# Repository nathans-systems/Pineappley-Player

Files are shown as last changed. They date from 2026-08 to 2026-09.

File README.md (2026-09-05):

# Pineappley-Player
My Open-Source, Custom built MP3 Player.
Using an ESP32-S3-Zero, cheap, available parts and a custom PCB I designed I've built a reliable and high quality audio playing MP3 Player.

picblack

## Hardware
- ESP32-S3-Zero
- 1.3 Inch I2C Oled
- Rotary Encoder
- TFT Micro SD Card Module
- KCX Bluetooth Emmiter
- TP4056 Charging Module
- MT3608 Boots Converter
- GY-PCM5102A
- 1800mah lithium battery
- Power Switch



## Key Features
- High Quality Audio
- Headphone Out
- Bluetooth Connectivity
- Micro SD card reader
- Rechargeable Battery



## Programming
The firmware is built on the PlatformIO and Arduino Framework.
You can upload and edit the firmware using Arduino C++ and flashing the ESP via the USB-C port under the OLED.

## PCB
I designed the PCB myself in KICAD. It features many through hole areas for each module, smd contacts for the KCX module and battery resistors and encoder capacitors.

## How Does it Work?
After loading your MP3 Files onto the SD card, the files are read over SPI to the ESP. After decoding, the PCM signal is sent over I2S to the PCM5102. The PCM5102 converts the digital audio to analog which can be read by the KCX Emitter.
The Pineappley Player utilises both cores of the ESP32-S3, forcing all audio tasks to core 0 to ensure clean audio as all other tasks such as drawing to the screen can run on core 1.

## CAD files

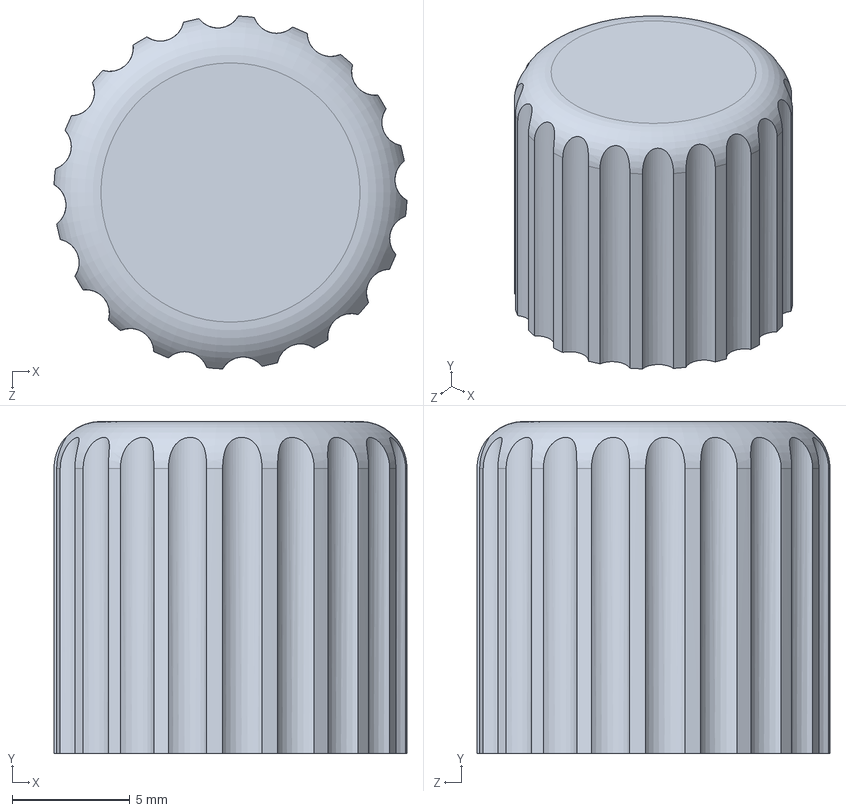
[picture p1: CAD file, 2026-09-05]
3D models/knob.SLDPRT
15.0 x 14.1 x 15.0 mm

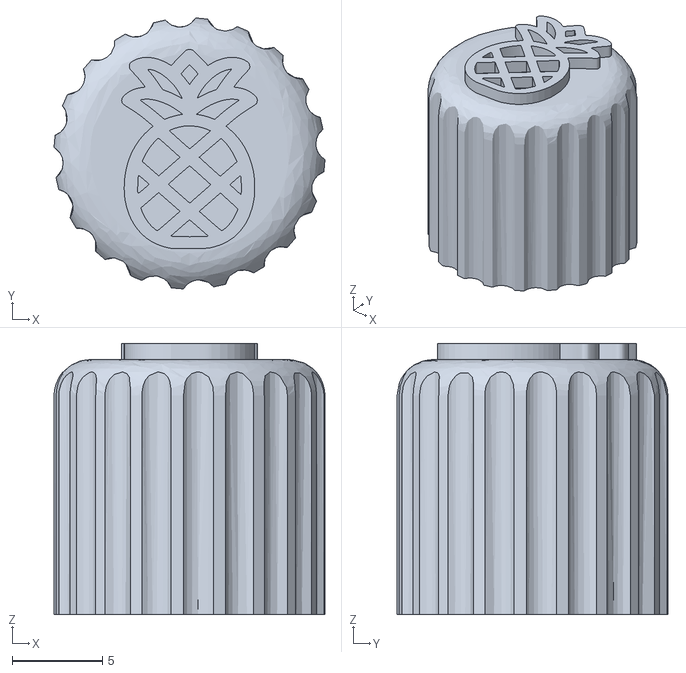
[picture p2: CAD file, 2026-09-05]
3D models/KnobWithLogo.stl
15.0 x 15.0 x 15.0

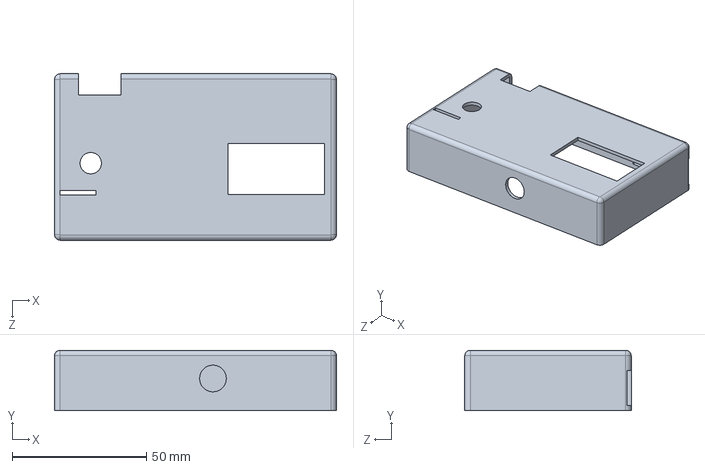
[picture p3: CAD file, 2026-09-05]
3D models/case.SLDPRT
105.0 x 22.5 x 62.0 mm

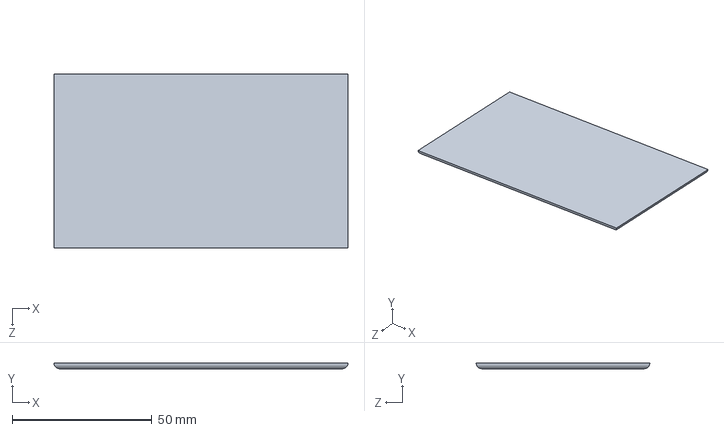
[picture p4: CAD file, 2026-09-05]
3D models/hatch.SLDPRT
105.0 x 2.00 x 62.0 mm

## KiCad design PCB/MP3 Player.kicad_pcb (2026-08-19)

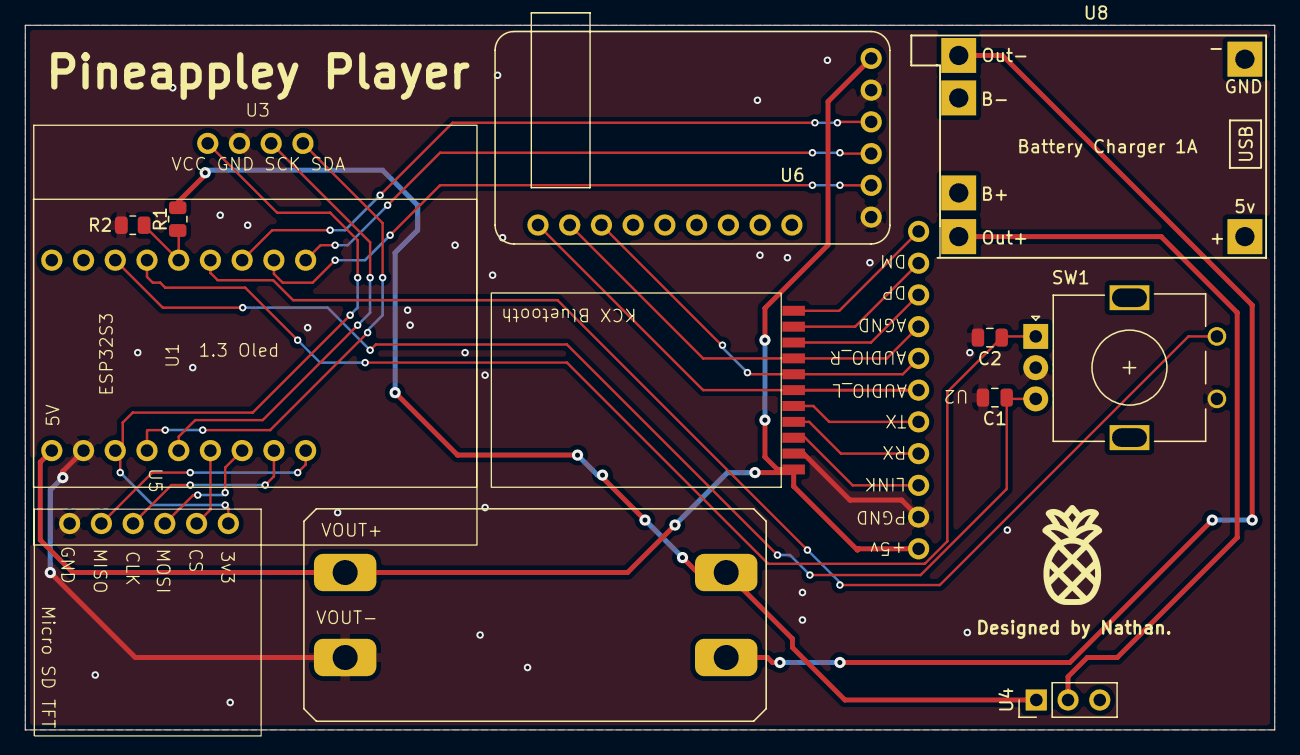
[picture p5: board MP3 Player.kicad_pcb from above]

Board: 2 copper layers, 100.0 x 56.4 mm, 13 parts (0 on the bottom side), 22 nets.

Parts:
C1, C2: 100nF; C_0805_2012Metric
R1, R2: 10K; R_0805_2012Metric
SW1: RotaryEncoder_Switch; RotaryEncoder_Alps_EC11E_Vertical_H20mm
U1: ESP32S3 MINI
U2: KCX Bluetooth
U3: 1.3 Oled
U4: PinHeader_1x03_P2.54mm_Vertical
U5: TFT MicroSD Module
U6: GY-PCM5102
U7: hw-045
U8: TP4056-18650

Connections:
+5V: U1.1 (5V), U2.1 (5V), U6.1 (VIN), U7.1 (VOUT+)
BAT+ OUT: R1.1, R2.2, U1.14 (GPIO11)
GND: C1.2, C2.2, R2.1, SW1.C, SW1.S2, U1.2 (GND), U2.2 (PGND), U3.2 (GND), U5.1 (GND), U6.2 (GND), U6.6 (SCK), U7.2 (VOUT-)
unnamed: U1.3 (3V3_OUT), U3.1 (VCC), U5.6 (3V3)
unnamed: U1.4 (GPIO1), U3.4 (SDA)
unnamed: U1.5 (GPIO2), U3.3 (SCK)
unnamed: U1.6 (GPIO3), U5.5 (CS)
unnamed: U1.7 (GPIO4), U5.4 (MOSI)
unnamed: U1.8 (GPIO5), U5.3 (CLK)
unnamed: U1.9 (GPIO6), U5.2 (MISO)
unnamed: U1.10 (GPIO7), U6.4 (DIN)
unnamed: U1.11 (GPIO8), U6.5 (BCK)
unnamed: U1.12 (GPIO9), U6.3 (LRCK)
unnamed: SW1.S1, U1.13 (GPIO10)
unnamed: C2.1, SW1.A, U1.15 (GPIO12)
unnamed: C1.1, SW1.B, U1.16 (GPIO13)
unnamed: U2.8 (AGND), U6.14 (AGND)
unnamed: U2.6 (AUDIO_L), U6.15 (LROUT)
unnamed: U2.7 (AUDIO_R), U6.13 (ROUT)
unnamed: U4.2 (IN), U8.1 (OUT+)
unnamed: R1.2, U4.1 (OUT), U7.3 (VIN+)
unnamed: U7.4 (VIN-), U8.4 (OUT-)

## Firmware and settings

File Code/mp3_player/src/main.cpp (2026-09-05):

#include <Arduino.h>
#include <Wire.h>
#include <SPI.h>
#include <SD.h>
#include <U8g2lib.h>
#include "Audio.h"
#include <vector>

#define OLED_SDA      1
#define OLED_SCL      2

#define SD_CS         3
#define SPI_MOSI      4
#define SPI_SCK       5
#define SPI_MISO      6

#define I2S_DOUT      7
#define I2S_BCLK      8
#define I2S_LRC       9

#define BATTERY_PIN   11

#define ENCODER_OUTA  12
#define ENCODER_OUTB  13
#define ENCODER_SW    10

enum UIState { SCREEN_MENU, SCREEN_PLAYER, SCREEN_SETTINGS };
UIState currentScreen = SCREEN_MENU;

enum PlayerButton { BTN_PREV, BTN_PLAY_PAUSE, BTN_NEXT, BTN_SHUFFLE, BTN_SEEK };
PlayerButton selectedPlayerBtn = BTN_PLAY_PAUSE;

enum SettingOption { SETTING_VOL_LIMIT, SETTING_BASS, SETTING_TREBLE, SETTING_BALANCE };
SettingOption selectedSetting = SETTING_VOL_LIMIT;
bool isSettingEditMode = false;

U8G2_SH1106_128X64_NONAME_F_HW_I2C u8g2(U8G2_R0, U8X8_PIN_NONE);
Audio audio;

std::vector<String> songList;
int currentTrackIndex = 0;
int playingTrackIndex = -1;
int menuScrollOffset = 0;
bool isPlaying = false;
bool isShuffle = false;

float maxVolumeLimit = 4.0f;
int bassBoost = 0;
int trebleBoost = 0;
int balanceLR = 0;

int currentVolume = 50;
bool showVolumeOverlay = false;

bool isSeeking = false;
uint32_t seekTargetSec = 0;

int batteryPercentage = 100;
float filteredVoltageMv = 0.0;
unsigned long lastBatteryCheck = 0;

void updateAudioVolume() {
  float targetVol = (currentVolume / 100.0f) * maxVolumeLimit;
  audio.setVolume(targetVol);
}

void applyEqualizerSettings() {
  audio.setTone(bassBoost, 0, trebleBoost);
  audio.setBalance(balanceLR);
}

int calculateLiPoPercentage(uint32_t mVolts) {
  const uint32_t MIN_VOLTAGE = 3200;
  const uint32_t MAX_VOLTAGE = 4200;

  if (mVolts >= MAX_VOLTAGE) return 100;
  if (mVolts <= MIN_VOLTAGE) return 0;

  return (int)(((float)(mVolts - MIN_VOLTAGE) / (MAX_VOLTAGE - MIN_VOLTAGE)) * 100.0f);
}

void readBatteryLevel() {
  uint32_t rawSum = 0;
  for (int i = 0; i < 32; i++) {
    rawSum += analogReadMilliVolts(BATTERY_PIN);
  }
  float currentPinMv = (float)rawSum / 32.0f;
  float currentBatMv = currentPinMv * 2.0f;

  if (filteredVoltageMv == 0.0) {
    filteredVoltageMv = currentBatMv;
  } else {
    filteredVoltageMv = (filteredVoltageMv * 0.85f) + (currentBatMv * 0.15f);
  }

  batteryPercentage = calculateLiPoPercentage((uint32_t)filteredVoltageMv);
}

void drawBatteryIndicator() {
  u8g2.setFont(u8g2_font_micro_tr);
  
  String pctStr = String(batteryPercentage) + "%";
  int textWidth = u8g2.getStrWidth(pctStr.c_str());
  int textX = 114 - textWidth; 
  u8g2.drawStr(textX, 8, pctStr.c_str());

  u8g2.drawFrame(115, 2, 11, 6);
  u8g2.drawVLine(126, 3, 4);

  int fillWidth = map(batteryPercentage, 0, 100, 0, 7);
  if (fillWidth > 0) {
    u8g2.drawBox(117, 4, fillWidth, 2);
  }
}

volatile int encoderStepDelta = 0; 
portMUX_TYPE encoderMux = portMUX_INITIALIZER_UNLOCKED;

void IRAM_ATTR encoderISR() {
  static uint8_t oldState = 0;
  static const int8_t knobStates[] = {0, -1, 1, 0, 1, 0, 0, -1, -1, 0, 0, 1, 0, 1, -1, 0};

  oldState <<= 2;
  if (digitalRead(ENCODER_OUTA)) oldState |= 0x02;
  if (digitalRead(ENCODER_OUTB)) oldState |= 0x01;
  oldState &= 0x0F;

  int8_t step = knobStates[oldState];
  if (step != 0) {
    portENTER_CRITICAL_ISR(&encoderMux);
    encoderStepDelta += step;
    portEXIT_CRITICAL_ISR(&encoderMux);
  }
}

bool lastRawBtnState = HIGH;
bool stableBtnState = HIGH;
unsigned long lastDebounceTime = 0;
const unsigned long DEBOUNCE_DELAY = 40;

unsigned long btnPressStartTime = 0;
int clickCount = 0;
unsigned long lastClickReleaseTime = 0;
bool longPressTriggered = false;

int marqueePosMenu = 0;
int marqueePosHeader = 0;
int marqueePosPlayer = 0;
unsigned long lastMarqueeUpdate = 0;

uint8_t barHeights[14] = {0};

const unsigned char epd_bitmap_pineapple_64x64 [] PROGMEM = {
  0x00, 0x00, 0x00, 0x00, 0x00, 0x00, 0x00, 0x00, 0x00, 0x00, 0x00, 0x80, 0x01, 0x00, 0x00, 0x00, 
  0x00, 0x00, 0x00, 0xc0, 0x03, 0x00, 0x00, 0x00, 0x00, 0x00, 0x7c, 0xe0, 0x07, 0x3e, 0x00, 0x00, 
  0x00, 0x00, 0xff, 0xf1, 0x8f, 0xff, 0x00, 0x00, 0x00, 0x80, 0xff, 0x7b, 0xde, 0xff, 0x01, 0x00, 
  0x00, 0x00, 0x8f, 0x3f, 0xfc, 0xf1, 0x00, 0x00, 0x00, 0x00, 0x0e, 0x1f, 0xf8, 0x70, 0x00, 0x00, 
  0x00, 0x00, 0x1c, 0x1c, 0x38, 0x38, 0x00, 0x00, 0x00, 0x00, 0x3c, 0x38, 0x1c, 0x3c, 0x00, 0x00, 
  0x00, 0x00, 0x38, 0x70, 0x0e, 0x1c, 0x00, 0x00, 0x00, 0x00, 0x70, 0xf0, 0x0f, 0x0e, 0x00, 0x00, 
  0x00, 0x00, 0xf0, 0xe0, 0x07, 0x0f, 0x00, 0x00, 0x00, 0x00, 0xff, 0xe0, 0x07, 0xff, 0x00, 0x00, 
  0x00, 0x80, 0xff, 0xc7, 0xe3, 0xff, 0x01, 0x00, 0x00, 0xc0, 0xe3, 0xcf, 0xf3, 0xc7, 0x03, 0x00, 
  0x00, 0xe0, 0x03, 0xfe, 0x7f, 0xc0, 0x07, 0x00, 0x00, 0xc0, 0x07, 0xf8, 0x1f, 0xe0, 0x03, 0x00, 
  0x00, 0x80, 0x0f, 0xf0, 0x0f, 0xf0, 0x01, 0x00, 0x00, 0x00, 0x1e, 0xe0, 0x07, 0x78, 0x00, 0x00, 
  0x00, 0x00, 0x3c, 0xc0, 0x03, 0x3c, 0x00, 0x00, 0x00, 0x00, 0x78, 0xc0, 0x03, 0x1e, 0x00, 0x00, 
  0x00, 0x00, 0xf0, 0xfc, 0x3f, 0x0f, 0x00, 0x00, 0x00, 0x00, 0xe0, 0xff, 0xff, 0x07, 0x00, 0x00, 
  0x00, 0x00, 0xc0, 0x1f, 0xf8, 0x03, 0x00, 0x00, 0x00, 0x00, 0xc0, 0x03, 0xc0, 0x03, 0x00, 0x00, 
  0x00, 0x00, 0xe0, 0x03, 0xc0, 0x07, 0x00, 0x00, 0x00, 0x00, 0xf0, 0x07, 0xe0, 0x0f, 0x00, 0x00, 
  0x00, 0x00, 0x38, 0x0f, 0xf0, 0x1c, 0x00, 0x00, 0x00, 0x00, 0x3c, 0x1e, 0x78, 0x3c, 0x00, 0x00, 
  0x00, 0x00, 0x1c, 0x3c, 0x3c, 0x38, 0x00, 0x00, 0x00, 0x00, 0x0e, 0x78, 0x1e, 0x70, 0x00, 0x00, 
  0x00, 0x00, 0x0e, 0xf0, 0x0f, 0x70, 0x00, 0x00, 0x00, 0x00, 0x07, 0xe0, 0x07, 0xe0, 0x00, 0x00, 
  0x00, 0x00, 0x07, 0xc0, 0x03, 0xe0, 0x00, 0x00, 0x00, 0x80, 0x03, 0xe0, 0x07, 0xc0, 0x01, 0x00, 
  0x00, 0x80, 0x03, 0xf0, 0x0f, 0xc0, 0x01, 0x00, 0x00, 0x80, 0x07, 0x78, 0x1e, 0xe0, 0x01, 0x00, 
  0x00, 0x80, 0x0f, 0x3c, 0x3c, 0xf0, 0x01, 0x00, 0x00, 0xc0, 0x1f, 0x1e, 0x78, 0xf8, 0x03, 0x00, 
  0x00, 0xc0, 0x39, 0x0f, 0xf0, 0x9c, 0x03, 0x00, 0x00, 0xc0, 0xf1, 0x07, 0xe0, 0x8f, 0x03, 0x00, 
  0x00, 0xc0, 0xe1, 0x03, 0xc0, 0x87, 0x03, 0x00, 0x00, 0xc0, 0xe1, 0x03, 0xc0, 0x87, 0x03, 0x00, 
  0x00, 0xc0, 0xf1, 0x03, 0xc0, 0x8f, 0x03, 0x00, 0x00, 0xc0, 0xf9, 0x07, 0xe0, 0x9f, 0x03, 0x00, 
  0x00, 0xc0, 0x3d, 0x0e, 0xf0, 0xbc, 0x03, 0x00, 0x00, 0xc0, 0x1f, 0x1c, 0x78, 0xf8, 0x03, 0x00, 
  0x00, 0xc0, 0x0f, 0x38, 0x3c, 0xf0, 0x03, 0x00, 0x00, 0x80, 0x07, 0x70, 0x1e, 0xe0, 0x01, 0x00, 
  0x00, 0x80, 0x03, 0xe0, 0x0f, 0xc0, 0x01, 0x00, 0x00, 0x80, 0x03, 0xc0, 0x03, 0xc0, 0x01, 0x00, 
  0x00, 0x80, 0x03, 0xc0, 0x03, 0xc0, 0x01, 0x00, 0x00, 0x00, 0x07, 0xe0, 0x07, 0xe0, 0x00, 0x00, 
  0x00, 0x00, 0x07, 0xf0, 0x0e, 0xe0, 0x00, 0x00, 0x00, 0x00, 0x0e, 0x78, 0x1c, 0x70, 0x00, 0x00, 
  0x00, 0x00, 0x0e, 0x3c, 0x38, 0x70, 0x00, 0x00, 0x00, 0x00, 0x1c, 0x1e, 0x70, 0x38, 0x00, 0x00, 
  0x00, 0x00, 0x3c, 0x07, 0xe0, 0x3c, 0x00, 0x00, 0x00, 0x00, 0xf8, 0x03, 0xc0, 0x1f, 0x00, 0x00, 
  0x00, 0x00, 0xf0, 0x07, 0xe0, 0x0f, 0x00, 0x00, 0x00, 0x00, 0xc0, 0xff, 0xff, 0x03, 0x00, 0x00, 
  0x00, 0x00, 0x00, 0xff, 0xff, 0x00, 0x00, 0x00, 0x00, 0x00, 0x00, 0xf0, 0x0f, 0x00, 0x00, 0x00
};

void AudioTask(void *pvParameters) {
  for (;;) {
    audio.loop();
    vTaskDelay(1 / portTICK_PERIOD_MS); 
  }
}

void showSplashScreen() {
  u8g2.clearBuffer();
  u8g2.drawXBMP(32, 0, 64, 64, epd_bitmap_pineapple_64x64);
  u8g2.sendBuffer();
  delay(50); 
}

String cleanFileName(String path) {
  int idx = path.lastIndexOf('/');
  if (idx != -1) path = path.substring(idx + 1);
  return path;
}

String formatTime(uint32_t seconds) {
  uint32_t m = seconds / 60;
  uint32_t s = seconds % 60;
  char buf[8];
  snprintf(buf, sizeof(buf), "%02u:%02u", m, s);
  return String(buf);
}

void scanSDCard() {
  File root = SD.open("/");
  if (!root) return;

  songList.clear();
  File file = root.openNextFile();
  while (file) {
    if (!file.isDirectory()) {
      String fileName = String(file.name());
      if (fileName.endsWith(".mp3") || fileName.endsWith(".MP3")) {
        if (!fileName.startsWith("/")) fileName = "/" + fileName;
        songList.push_back(fileName);
      }
    }
    file = root.openNextFile();
  }
}

void playTrack(int index) {
  if (songList.empty()) return;
  currentTrackIndex = index;
  playingTrackIndex = index; 
  String path = songList[currentTrackIndex];
  
  audio.connecttoFS(SD, path.c_str());
  isPlaying = true;
  marqueePosPlayer = 0;
  isSeeking = false;
  currentScreen = SCREEN_PLAYER;
}

void togglePlayPause() {
  if (songList.empty()) return;
  
  if (isPlaying) {
    audio.pauseResume();
    isPlaying = false;
  } else {
    if (audio.getAudioCurrentTime() == 0) {
      playTrack(currentTrackIndex);
    } else {
      audio.pauseResume();
      isPlaying = true;
    }
  }
}

int getNextTrackIndex() {
  if (songList.empty()) return 0;
  if (isShuffle && songList.size() > 1) {
    int next;
    do {
      next = random(0, songList.size());
    } while (next == playingTrackIndex);
    return next;
  }
  return (playingTrackIndex + 1) % songList.size();
}

void drawMenuUI() {
  u8g2.setFont(u8g2_font_6x10_tf);

  String headerText = "PLAYING: ";
  if (isPlaying && playingTrackIndex >= 0 && playingTrackIndex < (int)songList.size()) {
    headerText += cleanFileName(songList[playingTrackIndex]);
  } else {
    headerText += "[ Stop ]";
  }

  if (headerText.length() > 15) {
    String doubled = headerText + "    " + headerText;
    int subStart = (marqueePosHeader / 3) % (headerText.length() + 4);
    u8g2.drawStr(0, 9, doubled.substring(subStart, subStart + 15).c_str());
  } else {
    u8g2.drawStr(0, 9, headerText.c_str());
  }
  u8g2.drawHLine(0, 11, 128);

  if (currentTrackIndex < menuScrollOffset) {
    menuScrollOffset = currentTrackIndex;
  } else if (currentTrackIndex >= menuScrollOffset + 3) {
    menuScrollOffset = currentTrackIndex - 2;
  }

  for (int i = 0; i < 3; i++) {
    int itemIdx = menuScrollOffset + i;
    if (itemIdx >= (int)songList.size()) break;

    int y = 26 + (i * 16);
    String trackName = cleanFileName(songList[itemIdx]);

    if (itemIdx == currentTrackIndex) {
      u8g2.drawBox(0, y - 11, 128, 15);
      u8g2.setDrawColor(0);

      if (trackName.length() > 18) {
        String doubled = trackName + "   " + trackName;
        int subStart = (marqueePosMenu / 3) % (trackName.length() + 3);
        u8g2.drawStr(2, y, doubled.substring(subStart, subStart + 18).c_str());
      } else {
        u8g2.drawStr(2, y, trackName.c_str());
      }
      u8g2.setDrawColor(1);
    } else {
      if (trackName.length() > 18) trackName = trackName.substring(0, 15) + "..";
      u8g2.drawStr(2, y, trackName.c_str());
    }
  }
}

void drawPlayerUI() {
  u8g2.setFont(u8g2_font_6x10_tf);

  String trackName = (playingTrackIndex >= 0) ? cleanFileName(songList[playingTrackIndex]) : "";
  if (trackName.length() > 15) {
    String doubled = trackName + "    " + trackName;
    int subStart = (marqueePosPlayer / 3) % (trackName.length() + 4);
    u8g2.drawStr(0, 10, doubled.substring(subStart, subStart + 15).c_str());
  } else {
    u8g2.drawStr(0, 10, trackName.c_str());
  }
  u8g2.drawHLine(0, 13, 128);

  uint32_t curSec = isSeeking ? seekTargetSec : audio.getAudioCurrentTime();
  uint32_t totSec = audio.getAudioFileDuration();
  
  u8g2.drawStr(0, 25, formatTime(curSec).c_str());
  u8g2.drawFrame(35, 18, 58, 8);
  
  if (totSec > 0) {
    int fill = map(curSec, 0, totSec, 0, 54);
    u8g2.drawBox(37, 20, fill, 4);
  }
  u8g2.drawStr(96, 25, formatTime(totSec).c_str());

  uint16_t vu = audio.getVUlevel(); 
  uint8_t leftChannel = vu >> 8;
  uint8_t rightChannel = vu & 0xFF;
  uint8_t rawLevel = (leftChannel + rightChannel) / 2;

  uint8_t baseAmplitude = 1;
  if (isPlaying && rawLevel > 0) {
    float gainMultiplier = 3.0f; 
    float scaledLevel = rawLevel * gainMultiplier;
    baseAmplitude = map(constrain((int)scaledLevel, 0, 255), 0, 255, 1, 16);
  }

  for (int b = 0; b < 14; b++) {
    uint8_t targetHeight = 1;

    if (isPlaying && baseAmplitude > 1) {
      float eqWeight = 1.0;
      if (b < 3)       eqWeight = 1.20;
      else if (b < 7)  eqWeight = 1.05;
      else if (b < 11) eqWeight = 0.90;
      else             eqWeight = 0.75;

      int pseudoFreq = (int)(baseAmplitude * eqWeight) + random(-1, 2);
      targetHeight = constrain(pseudoFreq, 1, 16);
    }

    if (targetHeight >= barHeights[b]) {
      barHeights[b] = targetHeight;
    } else {
      if (barHeights[b] > 1) barHeights[b]--;
    }

    u8g2.drawBox(6 + (b * 9), 45 - barHeights[b], 5, barHeights[b]);
  }

  // BTN_PREV
  u8g2.setDrawColor(1);
  if (selectedPlayerBtn == BTN_PREV) {
    u8g2.drawBox(2, 49, 22, 14);
    u8g2.setDrawColor(0);
  }
  u8g2.drawVLine(6, 52, 8);
  u8g2.drawTriangle(12, 52, 12, 59, 8, 55);
  u8g2.drawTriangle(17, 52, 17, 59, 13, 55);

  // BTN_PLAY_PAUSE
  u8g2.setDrawColor(1);
  if (selectedPlayerBtn == BTN_PLAY_PAUSE) {
    u8g2.drawBox(27, 49, 22, 14);
    u8g2.setDrawColor(0);
  }
  if (isPlaying) {
    u8g2.drawBox(33, 52, 3, 8);
    u8g2.drawBox(38, 52, 3, 8);
  } else {
    u8g2.drawTriangle(34, 52, 34, 59, 41, 55);
  }

  // BTN_NEXT
  u8g2.setDrawColor(1);
  if (selectedPlayerBtn == BTN_NEXT) {
    u8g2.drawBox(52, 49, 22, 14);
    u8g2.setDrawColor(0);
  }
  u8g2.drawTriangle(56, 52, 56, 59, 61, 55);
  u8g2.drawTriangle(62, 52, 62, 59, 67, 55);
  u8g2.drawVLine(69, 52, 8);

  // BTN_SHUFFLE
  u8g2.setDrawColor(1);
  if (selectedPlayerBtn == BTN_SHUFFLE) {
    u8g2.drawBox(77, 49, 22, 14);
    u8g2.setDrawColor(0);
  }
  u8g2.drawLine(82, 53, 87, 58);
  u8g2.drawLine(82, 58, 87, 53);
  if (isShuffle) {
    u8g2.drawHLine(82, 60, 12);
  }

  // BTN_SEEK
  u8g2.setDrawColor(1);
  if (selectedPlayerBtn == BTN_SEEK) {
    u8g2.drawBox(102, 49, 24, 14);
    u8g2.setDrawColor(0);
  }
  u8g2.drawCircle(111, 55, 3);
  u8g2.drawLine(113, 57, 117, 61);

  u8g2.setDrawColor(1); 
}

void drawSettingsUI() {
  u8g2.setFont(u8g2_font_6x10_tf);
  u8g2.drawStr(0, 9, "SETTINGS");
  u8g2.drawHLine(0, 11, 128);

  const char* labels[] = {"Max Vol", "Bass", "Treble", "Balance"};
  String values[4];
  
  values[0] = String(maxVolumeLimit, 1) + "x";
  values[1] = (bassBoost > 0 ? "+" : "") + String(bassBoost) + "dB";
  values[2] = (trebleBoost > 0 ? "+" : "") + String(trebleBoost) + "dB";
  
  if (balanceLR == 0) values[3] = "Center";
  else if (balanceLR < 0) values[3] = "L +" + String(-balanceLR);
  else values[3] = "R +" + String(balanceLR);

  for (int i = 0; i < 4; i++) {
    int y = 24 + (i * 10);
    
    if (i == (int)selectedSetting) {
      if (isSettingEditMode) {
        u8g2.drawFrame(0, y - 8, 128, 10);
        u8g2.drawStr(2, y, labels[i]);
        u8g2.drawStr(80, y, values[i].c_str());
      } else {
        u8g2.drawBox(0, y - 8, 128, 10);
        u8g2.setDrawColor(0);
        u8g2.drawStr(2, y, labels[i]);
        u8g2.drawStr(80, y, values[i].c_str());
        u8g2.setDrawColor(1);
      }
    } else {
      u8g2.drawStr(2, y, labels[i]);
      u8g2.drawStr(80, y, values[i].c_str());
    }
  }
}

void drawSeekOverlay() {
  u8g2.drawBox(10, 15, 108, 36);
  u8g2.setDrawColor(0);
  u8g2.drawFrame(11, 16, 106, 34);

  u8g2.setFont(u8g2_font_micro_tr);
  u8g2.drawStr(18, 25, "SEEKING TRACK...");

  u8g2.drawFrame(18, 30, 72, 10);
  uint32_t totSec = audio.getAudioFileDuration();
  if (totSec > 0) {
    int fill = map(seekTargetSec, 0, totSec, 0, 68);
    u8g2.drawBox(20, 32, fill, 6);
  }

  u8g2.setFont(u8g2_font_micro_tr);
  u8g2.drawStr(18, 46, formatTime(seekTargetSec).c_str());
  u8g2.drawStr(65, 46, ("/ " + formatTime(totSec)).c_str());

  u8g2.setDrawColor(1);
}

void drawVolumeOverlay() {
  u8g2.drawBox(10, 15, 108, 36);
  u8g2.setDrawColor(0);
  u8g2.drawFrame(11, 16, 106, 34);

  u8g2.setFont(u8g2_font_6x10_tf);
  u8g2.drawStr(18, 28, "VOLUME");

  u8g2.drawFrame(18, 33, 70, 10);
  
  int fillWidth = map(currentVolume, 0, 100, 0, 66);
  u8g2.drawBox(20, 35, fillWidth, 6);

  u8g2.drawStr(92, 42, (String(currentVolume) + "%").c_str());
  
  u8g2.setDrawColor(1); 
}

void renderUI() {
  u8g2.clearBuffer();

  switch (currentScreen) {
    case SCREEN_MENU:     drawMenuUI(); break;
    case SCREEN_PLAYER:   drawPlayerUI(); break;
    case SCREEN_SETTINGS: drawSettingsUI(); break;
  }

  drawBatteryIndicator();

  if (isSeeking) {
    drawSeekOverlay();
  } else if (showVolumeOverlay) {
    drawVolumeOverlay();
  }

  u8g2.sendBuffer();
}
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
void loop() {
  if (millis() - lastBatteryCheck > 3000) {
    readBatteryLevel();
    lastBatteryCheck = millis();
  }

  if (millis() - lastMarqueeUpdate > 120) {
    marqueePosMenu++;
    marqueePosHeader++;
    marqueePosPlayer++;
    lastMarqueeUpdate = millis();
    renderUI();
  }

  int steps = 0;
  if (encoderStepDelta != 0) {
    portENTER_CRITICAL(&encoderMux);
    steps = encoderStepDelta / 4; 
    if (steps != 0) {
      encoderStepDelta %= 4;      
    }
    portEXIT_CRITICAL(&encoderMux);
  }

  if (steps != 0) {
    bool isCW = (steps > 0);
    int stepMagnitude = abs(steps);

    for (int i = 0; i < stepMagnitude; i++) {
      if (isSeeking) {
        uint32_t total = audio.getAudioFileDuration();
        if (isCW) {
          seekTargetSec = min(total, seekTargetSec + 5);
        } else {
          seekTargetSec = (seekTargetSec > 5) ? seekTargetSec - 5 : 0;
        }
      }
      else if (showVolumeOverlay) {
        if (isCW) currentVolume = min(100, currentVolume + 2);
        else      currentVolume = max(0, currentVolume - 2);
        
        updateAudioVolume();
      } 
      else if (currentScreen == SCREEN_SETTINGS) {
        if (isSettingEditMode) {
          if (selectedSetting == SETTING_VOL_LIMIT) {
            maxVolumeLimit = constrain(maxVolumeLimit + (isCW ? 0.5f : -0.5f), 1.0f, 21.0f);
            updateAudioVolume();
          } else if (selectedSetting == SETTING_BASS) {
            bassBoost = constrain(bassBoost + (isCW ? 1 : -1), -12, 12);
            applyEqualizerSettings();
          } else if (selectedSetting == SETTING_TREBLE) {
            trebleBoost = constrain(trebleBoost + (isCW ? 1 : -1), -12, 12);
            applyEqualizerSettings();
          } else if (selectedSetting == SETTING_BALANCE) {
            balanceLR = constrain(balanceLR + (isCW ? 1 : -1), -16, 16);
            applyEqualizerSettings();
          }
        } else {
          if (isCW) {
            selectedSetting = (SettingOption)((selectedSetting + 1) % 4);
          } else {
            selectedSetting = (SettingOption)((selectedSetting + 3) % 4);
          }
        }
      }
      else if (currentScreen == SCREEN_MENU) {
        if (isCW) {
          currentTrackIndex = (currentTrackIndex + 1) % songList.size();
        } else {
          currentTrackIndex = (currentTrackIndex - 1 + songList.size()) % songList.size();
        }
        marqueePosMenu = 0;
      } 
      else if (currentScreen == SCREEN_PLAYER) {
        if (isCW) {
          selectedPlayerBtn = (PlayerButton)((selectedPlayerBtn + 1) % 5);
        } else {
          selectedPlayerBtn = (PlayerButton)((selectedPlayerBtn + 4) % 5);
        }
      }
    }
  }

  bool rawReading = digitalRead(ENCODER_SW);

  if (rawReading != lastRawBtnState) {
    lastDebounceTime = millis();
  }

  if ((millis() - lastDebounceTime) > DEBOUNCE_DELAY) {
    if (rawReading != stableBtnState) {
      stableBtnState = rawReading;

      if (stableBtnState == LOW) {
        btnPressStartTime = millis();
        longPressTriggered = false;
      } else {
        if (!longPressTriggered) {
          clickCount++;
          lastClickReleaseTime = millis();
        }
      }
    }
  }
  lastRawBtnState = rawReading;

  if (stableBtnState == LOW && !longPressTriggered) {
    if (millis() - btnPressStartTime >= 1500) {
      if (!isSeeking) {
        showVolumeOverlay = !showVolumeOverlay;
        longPressTriggered = true;
        clickCount = 0; 
      }
    }
  }

  if (clickCount > 0 && (millis() - lastClickReleaseTime > 300)) {
    if (clickCount == 1) {
      if (isSeeking) {
        uint32_t fileDuration = audio.getAudioFileDuration();
        if (fileDuration > 0) {
          seekTargetSec = constrain(seekTargetSec, (uint32_t)0, fileDuration - 1);
        }
        
        audio.setAudioPlayPosition(seekTargetSec); 
        
        if (!isPlaying) {
          audio.pauseResume();
          isPlaying = true;
        }

        isSeeking = false;
      } else if (showVolumeOverlay) {
        showVolumeOverlay = false;
      } else if (currentScreen == SCREEN_SETTINGS) {
        isSettingEditMode = !isSettingEditMode;
      } else if (currentScreen == SCREEN_MENU) {
        playTrack(currentTrackIndex);
      } else if (currentScreen == SCREEN_PLAYER) {
        if (selectedPlayerBtn == BTN_PLAY_PAUSE) {
          togglePlayPause();
        } else if (selectedPlayerBtn == BTN_PREV) {
          int prev = (playingTrackIndex - 1 + songList.size()) % songList.size();
          playTrack(prev);
        } else if (selectedPlayerBtn == BTN_NEXT) {
          playTrack(getNextTrackIndex());
        } else if (selectedPlayerBtn == BTN_SHUFFLE) {
          isShuffle = !isShuffle; 
        } else if (selectedPlayerBtn == BTN_SEEK) {
          isSeeking = true;
          seekTargetSec = audio.getAudioCurrentTime();
        }
      }
    } 
    else if (clickCount == 2) {
      isSeeking = false;
      showVolumeOverlay = false;
      isSettingEditMode = false;
      currentScreen = SCREEN_MENU;
    } 
    else if (clickCount >= 3) {
      isSeeking = false;
      showVolumeOverlay = false;
      isSettingEditMode = false;
      currentScreen = SCREEN_SETTINGS;
    }

    clickCount = 0;
  }
}

void audio_eof_mp3(const char *info) {
  playTrack(getNextTrackIndex());
}
